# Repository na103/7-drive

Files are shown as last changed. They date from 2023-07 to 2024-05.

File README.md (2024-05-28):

# 7-drive
7-drive is a remake of an Amiga accessory made by the company Logica in Italy, it is installed on the external drive port and can show, in the 7-segment display, the activity of the df0 or df1 drive.
<br>
it's not particularly useful, maybe it was in the past when you spent your time copying hundreds of floppies.<br>
however it seems nice to me as an object to add to our amiga.
<br><br>
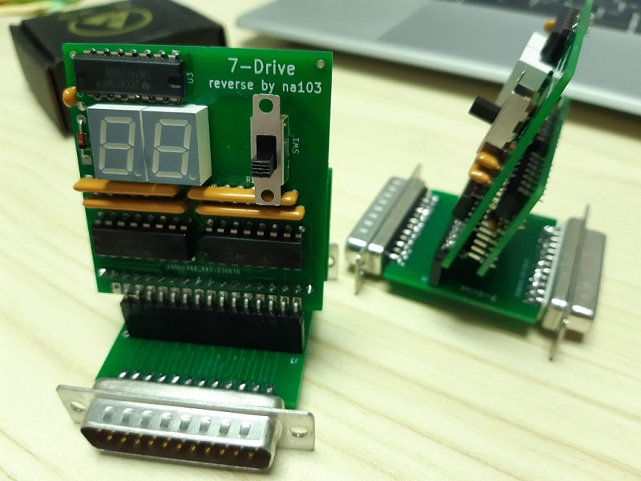
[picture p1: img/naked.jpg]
7-drive

<br>
you can see 7-drive in action in this [short video](https://youtu.be/NdRC49Pznj0)
<br><br>

## Bill of materials
| Qt. | Description | Designator | Mouser  Part | Note |
|:---:|---|---|---|---|
|1 |74LS27 | U2 |SN74LS27N | |
|1 |74LS00 | U3 |SN74LS00N | |
|2 |Decade up-down counter| U4 U5 |CD40110BE | |
|2 |7 segment display | DS1 DS2 |TDSO3160-L | |
|2 |Diode 1N4148 | D1 D2 |1N4148 | |
|1 |Resistor 3.9K | R1 |MFR25SFTE26-3K9 | |
|4 |Resistor net. 220R  | RN1 - RN4 |4608X-102-221LF | |
|1 |Capacitor 4.7 nF | C1 |K472J20C0GF5TH5 | |
|2 |Capacitor 100 nF | C2 C3 |K104K15X7RF5TH5 | |
|1 |Switch 2P3T | SW1 |EG1201A | |
|1 |Db23 male | J1 | | on ebay or [amigatore.eu](https://amigastore.eu/en/790-db23-male-connector.html) |
|1 |Db23 female | J2 | | on ebay or [amigastore.eu](https://amigastore.eu/en/810-db23-female-connector.html) |
|1 |15-Pin female header| J3 |15Fx1-254mm | |
|1 |18-Pin male header  | J5 |22-28-4183 | |
|1 |15-Pin male header  | J6 |22-28-8152 | |

here you can find the mouser project with all the components, Db23 connectors excluded.
[https://www.mouser.com/ProjectManager/ProjectDetail.aspx?AccessID=75b1d9bf4b](https://www.mouser.com/ProjectManager/ProjectDetail.aspx?AccessID=75b1d9bf4b)

## Building notes

* you can see [here](https://github.com/na103/7-drive/tree/main/img) the steps to follow to build the board.
* gerber of the three board is inside kicad projects
* switch in upper position show DF0 activity, down DF1
* is avaible an optional 3d printed case. thanks to Roberto Camparini for stl file

<br>
If you found this my work useful, please consider buying me a cup of coffee if you want:<br>


# License

This work is licensed under a Creative Commons Attribution 4.0 International License. See [https://creativecommons.org/licenses/by/4.0/](https://creativecommons.org/licenses/by/4.0/).

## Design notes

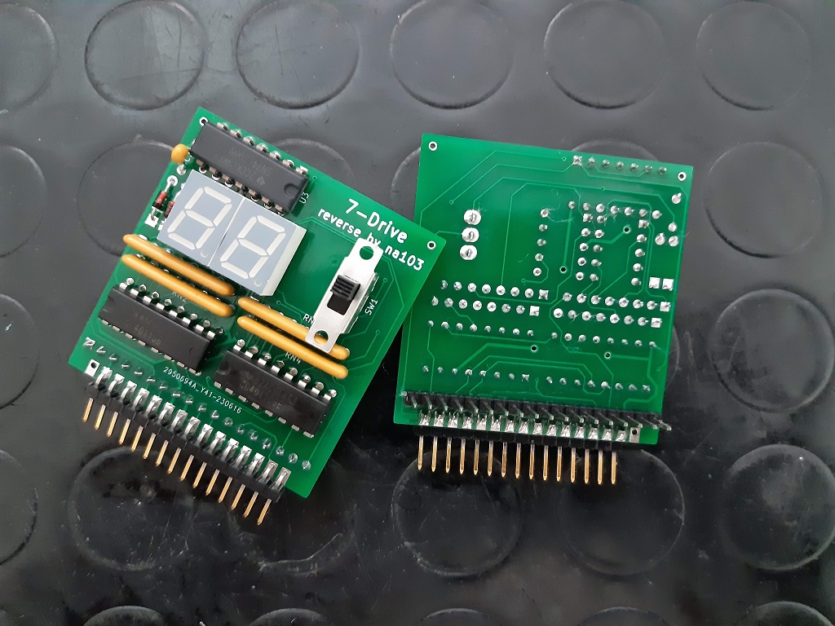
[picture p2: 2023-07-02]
img/cs3.jpg

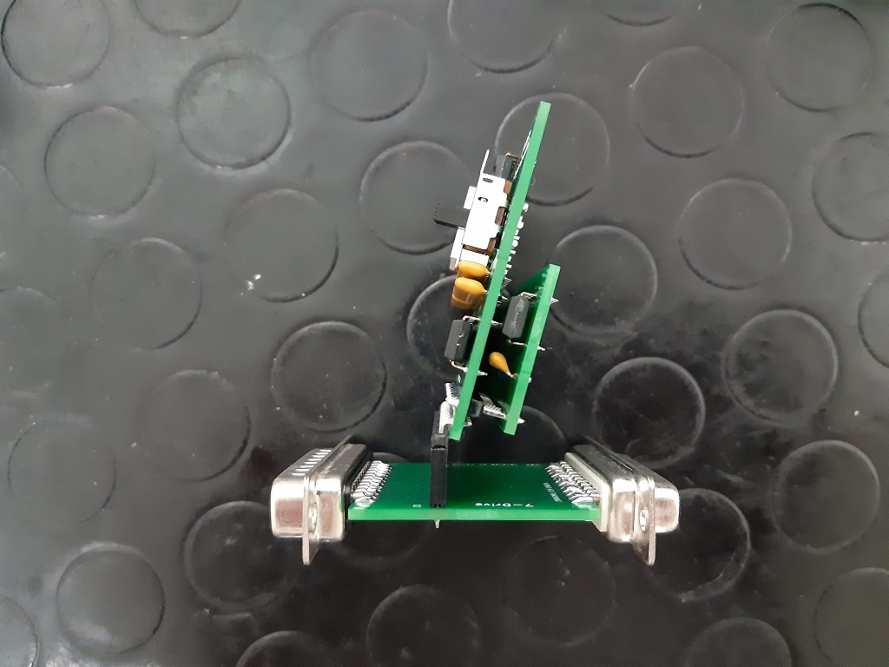
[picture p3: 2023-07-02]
img/cs1_cs2_cs3.jpg

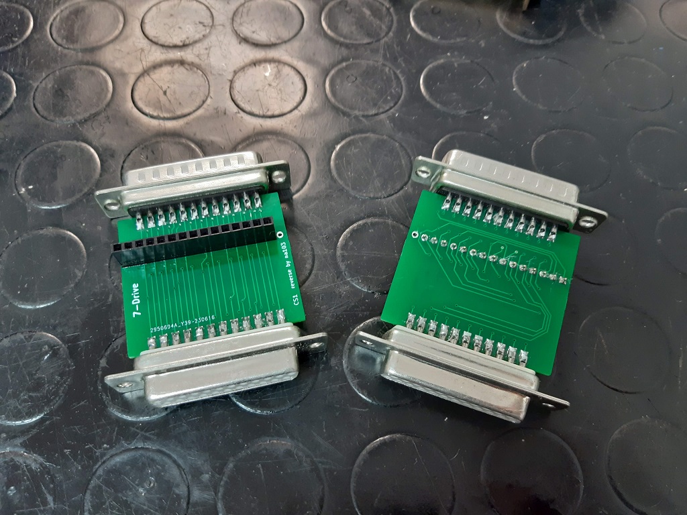
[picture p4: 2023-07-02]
img/cs1.jpg

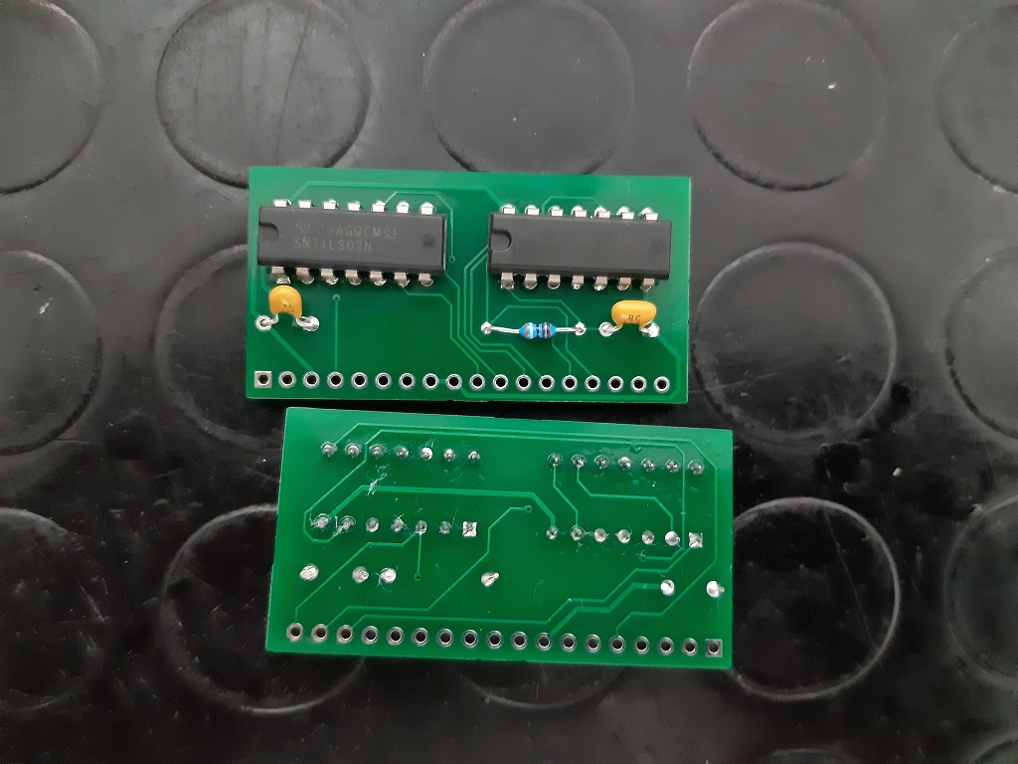
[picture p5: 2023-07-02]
img/cs2.jpg

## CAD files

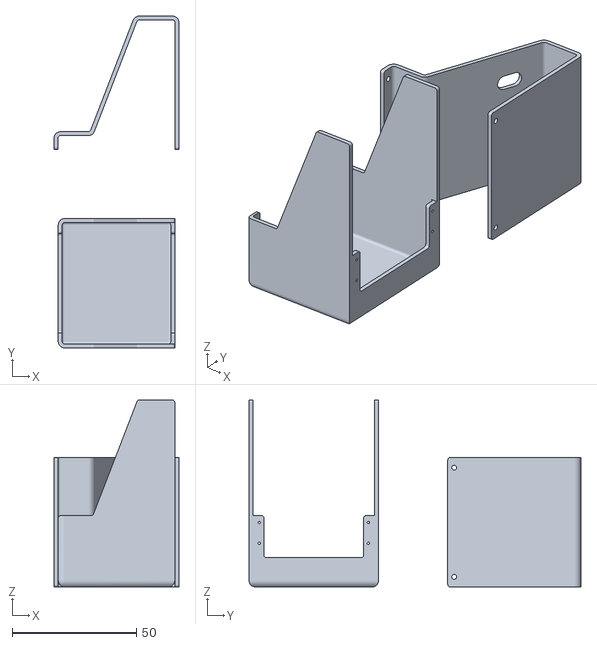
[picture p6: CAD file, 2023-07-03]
3d-print/7-Drive.stl
50.4 x 133.8 x 75.4

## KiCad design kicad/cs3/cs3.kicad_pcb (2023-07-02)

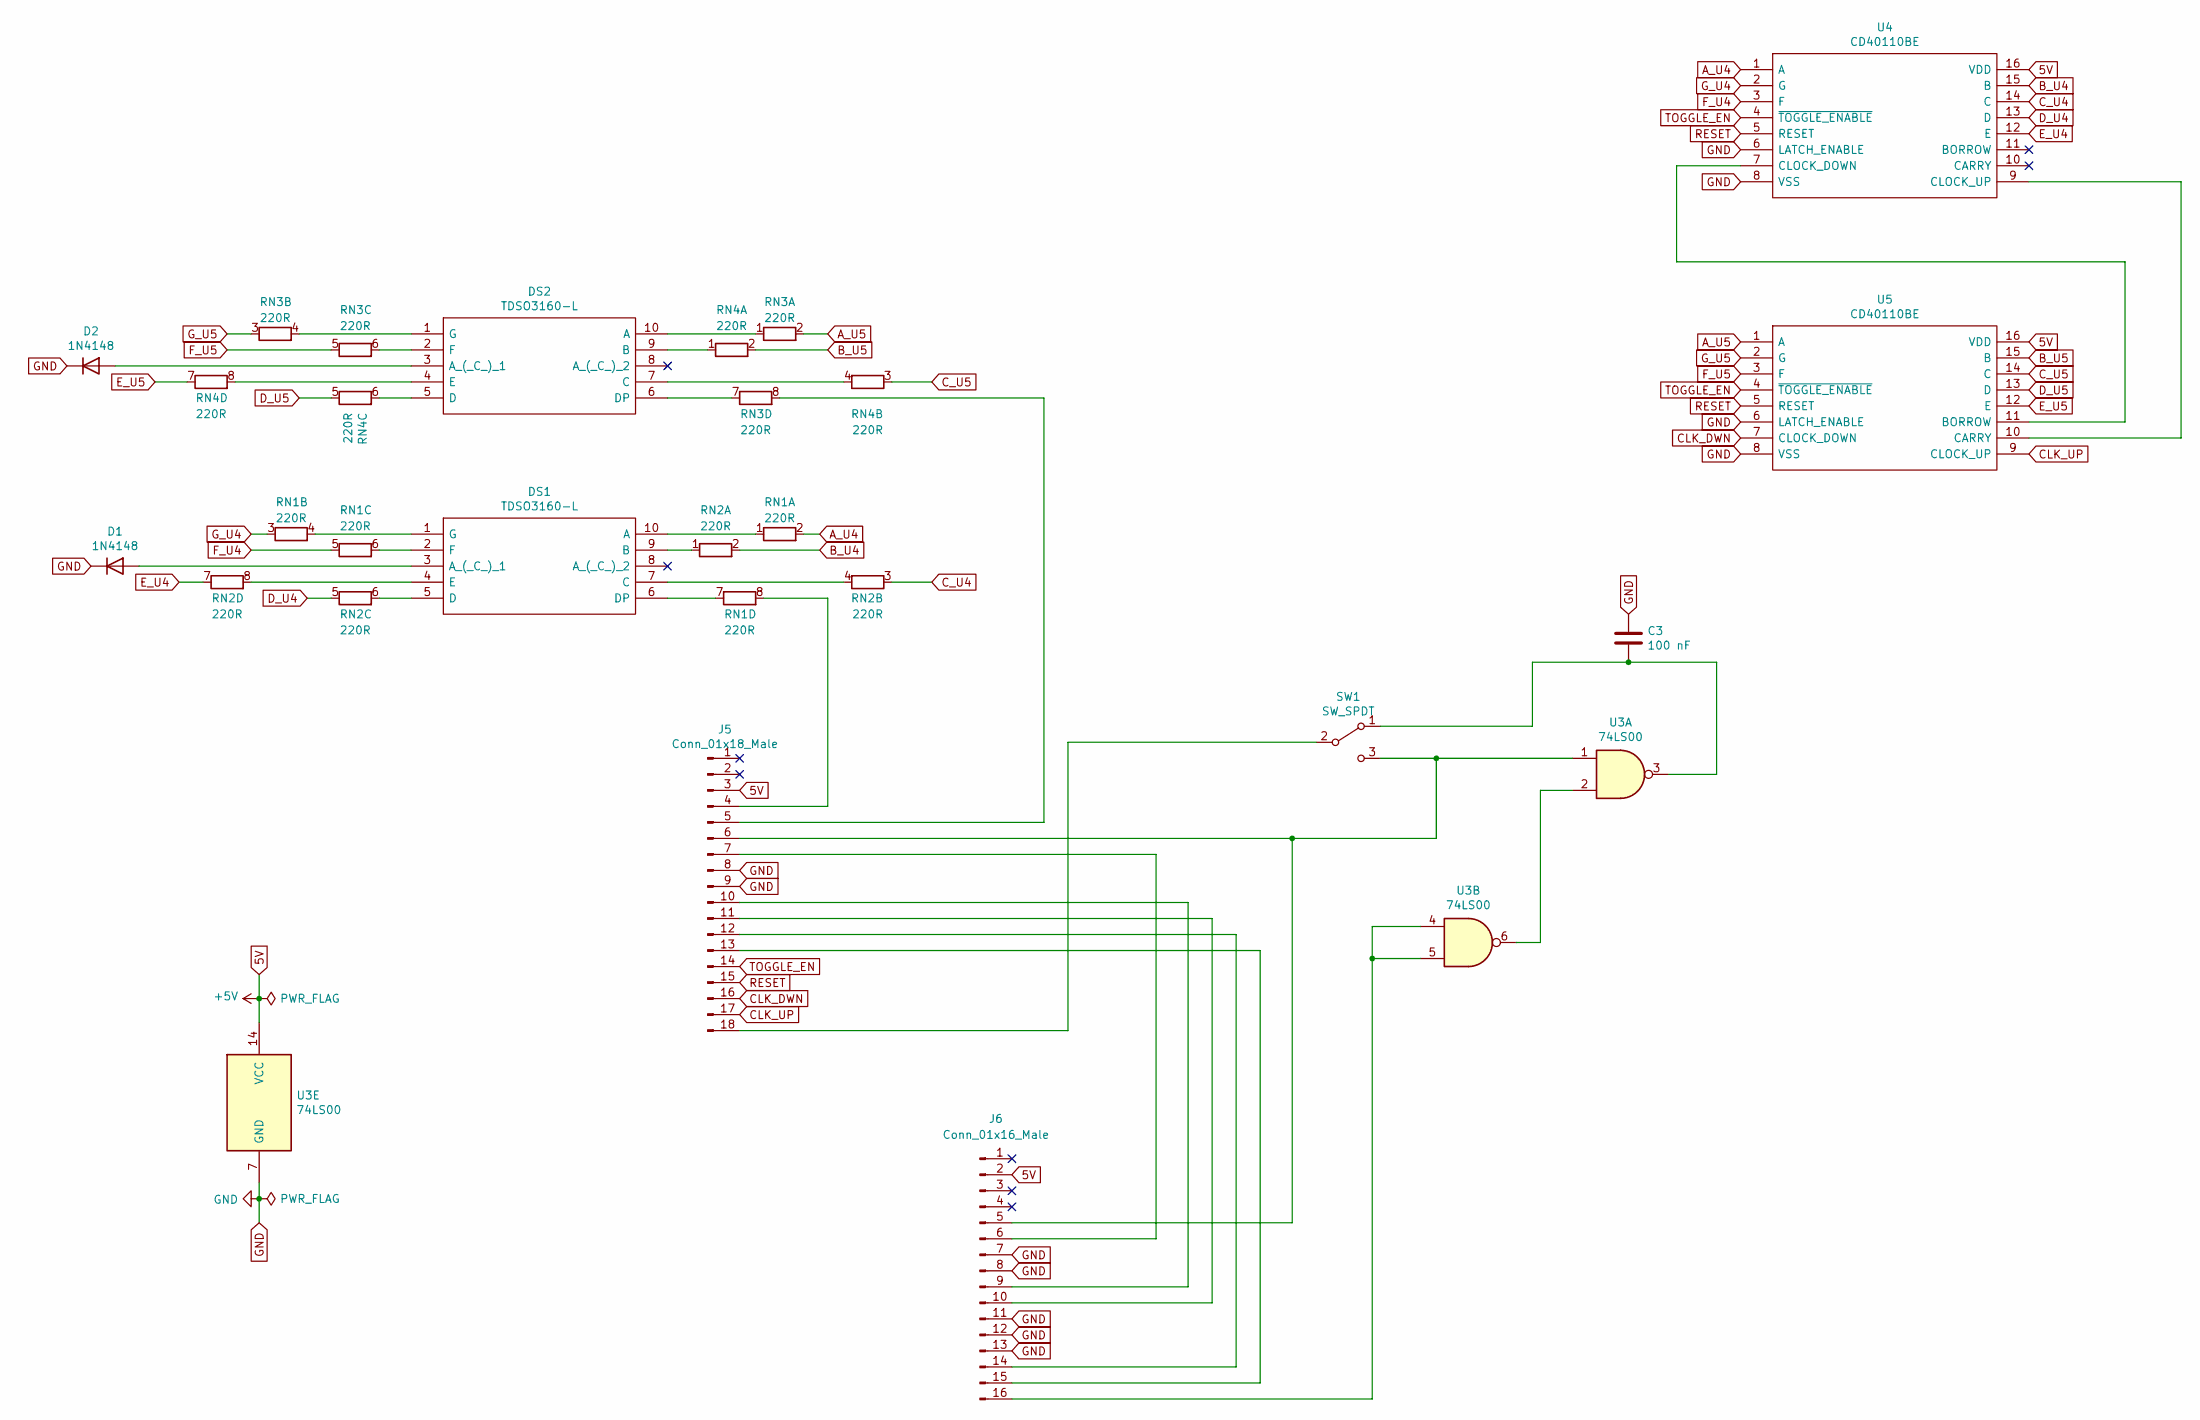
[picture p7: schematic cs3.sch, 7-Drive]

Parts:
C3: 100 nF; C_Disc_D6.0mm_W2.5mm_P5.00mm
D1, D2: 1N4148; D_A-405_P7.62mm_Horizontal
DS1, DS2: TDSO3160-L; TDSO3160L; Manufacturer_Part_Number TDSO3160-L; Mouser Part Number 78-TDSO3160-L
J5: Conn_01x18_Male; PinHeader_1x18_P2.54mm_Vertical
J6: Conn_01x16_Male; PinHeader_1x16_P2.54mm_Horizontal
RN1, RN2, RN3, RN4: 220R; R_Array_SIP8
SW1: SW_SPDT; SW_Slide_1P2T_SPDT
U3: 74LS00; DIP-14_W7.62mm
U4, U5: CD40110BE; DIP794W53P254L1930H508Q16N; Manufacturer_Part_Number CD40110BE; Mouser Part Number 595-CD40110BE

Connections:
5V: J5.3, J6.2, U3.14 (VCC), U4.16 (VDD), U5.16 (VDD)
A_U4: RN1.2 (R1.2), U4.1 (A)
A_U5: RN3.2 (R1.2), U5.1 (A)
B_U4: RN2.2 (R1.2), U4.15 (B)
B_U5: RN4.2 (R1.2), U5.15 (B)
CLK_DWN: J5.16, U5.7 (CLOCK_DOWN)
CLK_UP: J5.17, U5.9 (CLOCK_UP)
C_U4: RN2.3 (R2.1), U4.14 (C)
C_U5: RN4.3 (R2.1), U5.14 (C)
D_U4: RN2.5 (R3.1), U4.13 (D)
D_U5: RN4.5 (R3.1), U5.13 (D)
E_U4: RN2.7 (R4.1), U4.12 (E)
E_U5: RN4.7 (R4.1), U5.12 (E)
F_U4: RN1.5 (R3.1), U4.3 (F)
F_U5: RN3.5 (R3.1), U5.3 (F)
GND: C3.1, D1.1 (K), D2.1 (K), J5.8, J5.9, J6.7, J6.8, J6.11, J6.12, J6.13, U3.7 (GND), U4.6 (LATCH_ENABLE), U4.8 (VSS), U5.6 (LATCH_ENABLE), U5.8 (VSS)
G_U4: RN1.3 (R2.1), U4.2 (G)
G_U5: RN3.3 (R2.1), U5.2 (G)
unnamed: C3.2, SW1.1 (A), U3.3
unnamed: D1.2 (A), DS1.3 (A_(_C_)_1)
unnamed: D2.2 (A), DS2.3 (A_(_C_)_1)
unnamed: DS1.1 (G), RN1.4 (R2.2)
unnamed: DS1.2 (F), RN1.6 (R3.2)
unnamed: DS1.4 (E), RN2.8 (R4.2)
unnamed: DS1.5 (D), RN2.6 (R3.2)
unnamed: DS1.6 (DP), RN1.7 (R4.1)
unnamed: DS1.7 (C), RN2.4 (R2.2)
unnamed: DS1.9 (B), RN2.1 (R1.1)
unnamed: DS1.10 (A), RN1.1 (R1.1)
unnamed: DS2.1 (G), RN3.4 (R2.2)
unnamed: DS2.2 (F), RN3.6 (R3.2)
unnamed: DS2.4 (E), RN4.8 (R4.2)
unnamed: DS2.5 (D), RN4.6 (R3.2)
unnamed: DS2.6 (DP), RN3.7 (R4.1)
unnamed: DS2.7 (C), RN4.4 (R2.2)
unnamed: DS2.9 (B), RN4.1 (R1.1)
unnamed: DS2.10 (A), RN3.1 (R1.1)
unnamed: J5.4, RN1.8 (R4.2)
unnamed: J5.5, RN3.8 (R4.2)
unnamed: J5.6, J6.5, SW1.3 (C), U3.1
unnamed: J5.7, J6.6
unnamed: J5.10, J6.9
unnamed: J5.11, J6.10
unnamed: J5.12, J6.14
unnamed: J5.13, J6.15
unnamed: J5.18, SW1.2 (B)
unnamed: J6.16, U3.4, U3.5
unnamed: U3.2, U3.6
unnamed: U4.7 (CLOCK_DOWN), U5.11 (BORROW)
unnamed: U4.9 (CLOCK_UP), U5.10 (CARRY)
RESET: J5.15, U4.5 (RESET), U5.5 (RESET)
TOGGLE_EN: J5.14, U4.4 (~TOGGLE_ENABLE), U5.4 (~TOGGLE_ENABLE)

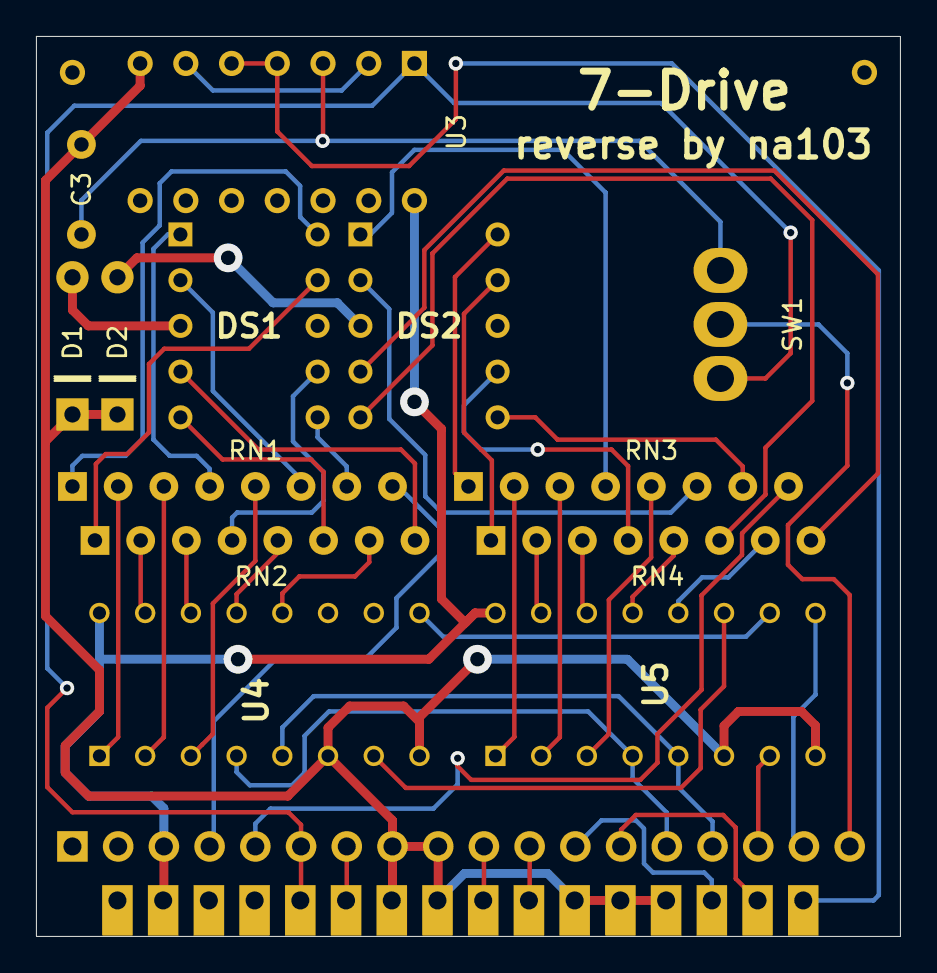
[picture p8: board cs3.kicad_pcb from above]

Board: 2 copper layers, 48.0 x 50.0 mm, 15 parts (1 on the bottom side), 52 nets.

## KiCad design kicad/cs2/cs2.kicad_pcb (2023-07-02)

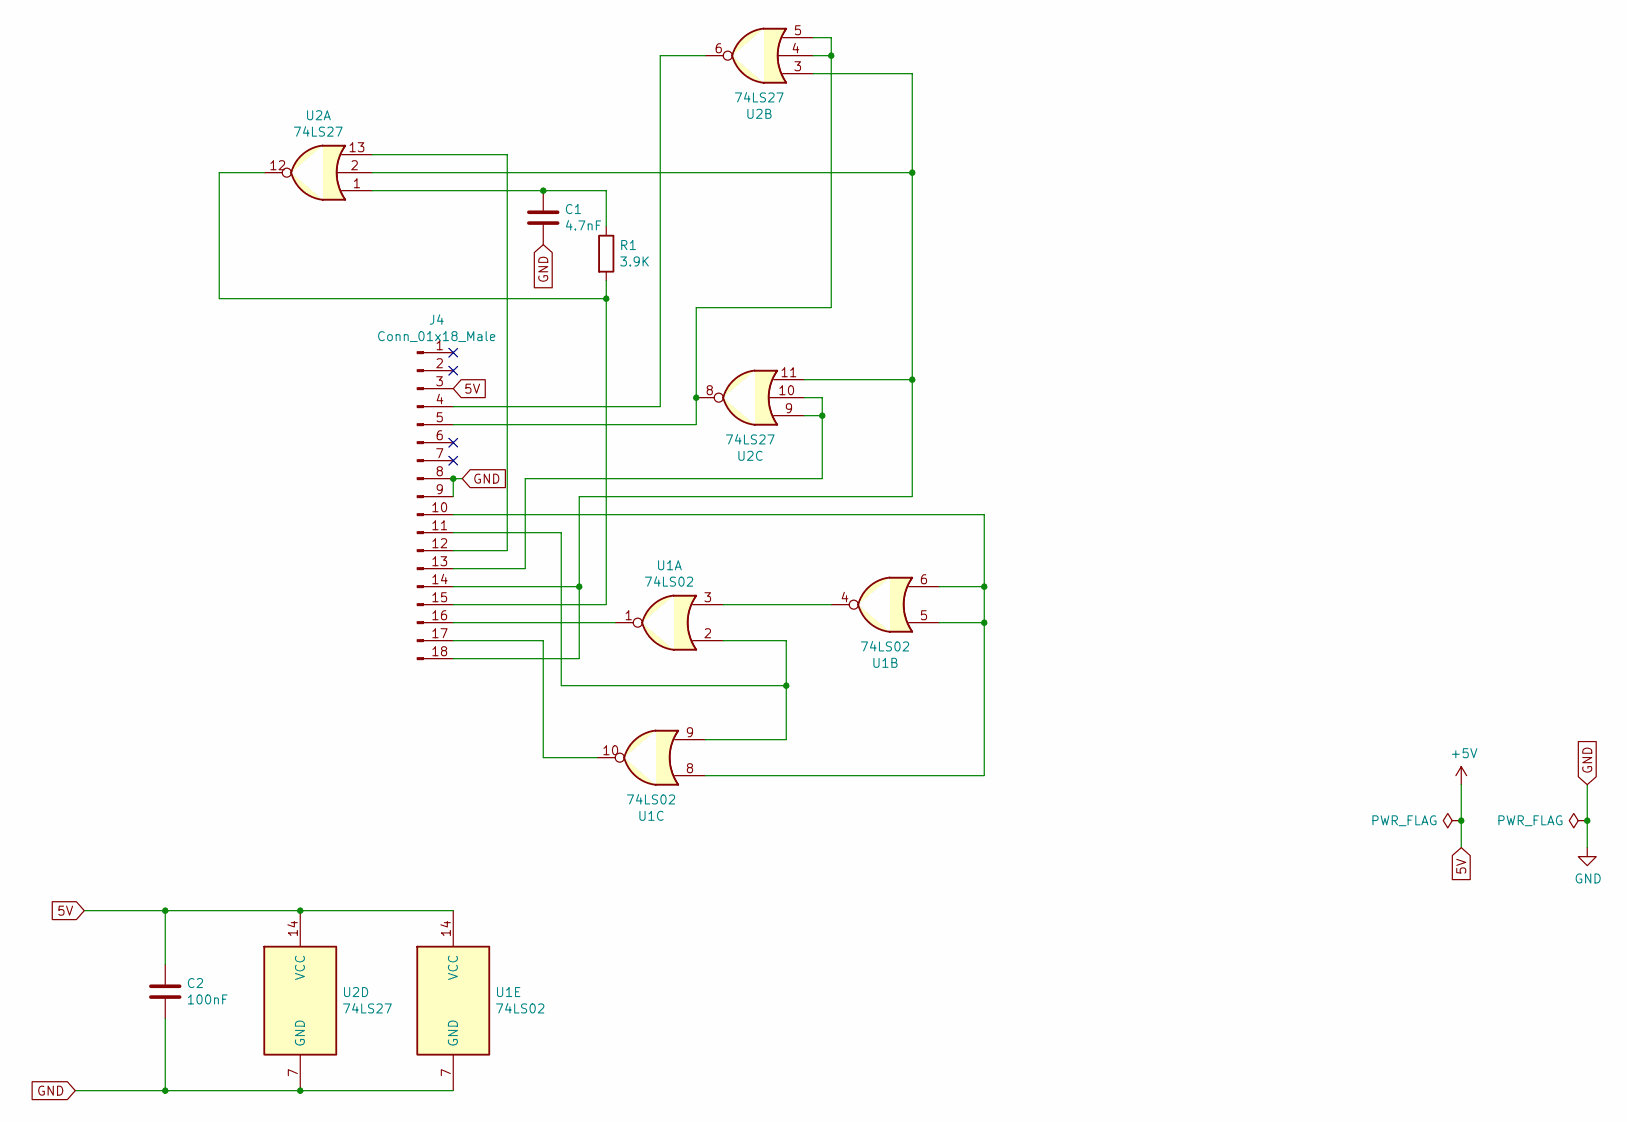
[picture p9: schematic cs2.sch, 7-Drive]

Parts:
C1: 4.7nF; C_Disc_D4.3mm_W1.9mm_P5.00mm
C2: 100nF; C_Disc_D4.3mm_W1.9mm_P5.00mm
J4: Conn_01x18_Male; PinHeader_1x18_P2.54mm_Vertical
R1: 3.9K; R_Axial_DIN0207_L6.3mm_D2.5mm_P10.16mm_Horizontal
U1: 74LS02; DIP-14_W7.62mm
U2: 74LS27; DIP-14_W7.62mm

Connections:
5V: C2.1, J4.3, U1.14 (VCC), U2.14 (VCC)
GND: C1.2, C2.2, J4.8, J4.9, U1.7 (GND), U2.7 (GND)
unnamed: C1.1, R1.1, U2.1
unnamed: J4.4, U2.6
unnamed: J4.5, U2.4, U2.5, U2.8
unnamed: J4.10, U1.5, U1.6, U1.8
unnamed: J4.11, U1.2, U1.9
unnamed: J4.12, U2.13
unnamed: J4.13, U2.9, U2.10
unnamed: J4.14, J4.18, U2.2, U2.3, U2.11
unnamed: J4.15, R1.2, U2.12
unnamed: J4.16, U1.1
unnamed: J4.17, U1.10
unnamed: U1.3, U1.4

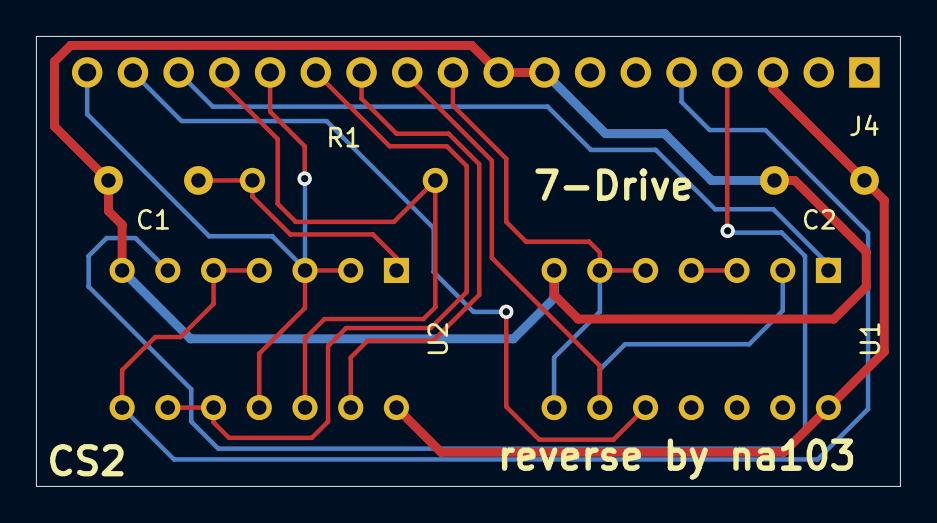
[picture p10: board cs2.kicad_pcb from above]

Board: 2 copper layers, 48.0 x 25.0 mm, 6 parts (0 on the bottom side), 14 nets.

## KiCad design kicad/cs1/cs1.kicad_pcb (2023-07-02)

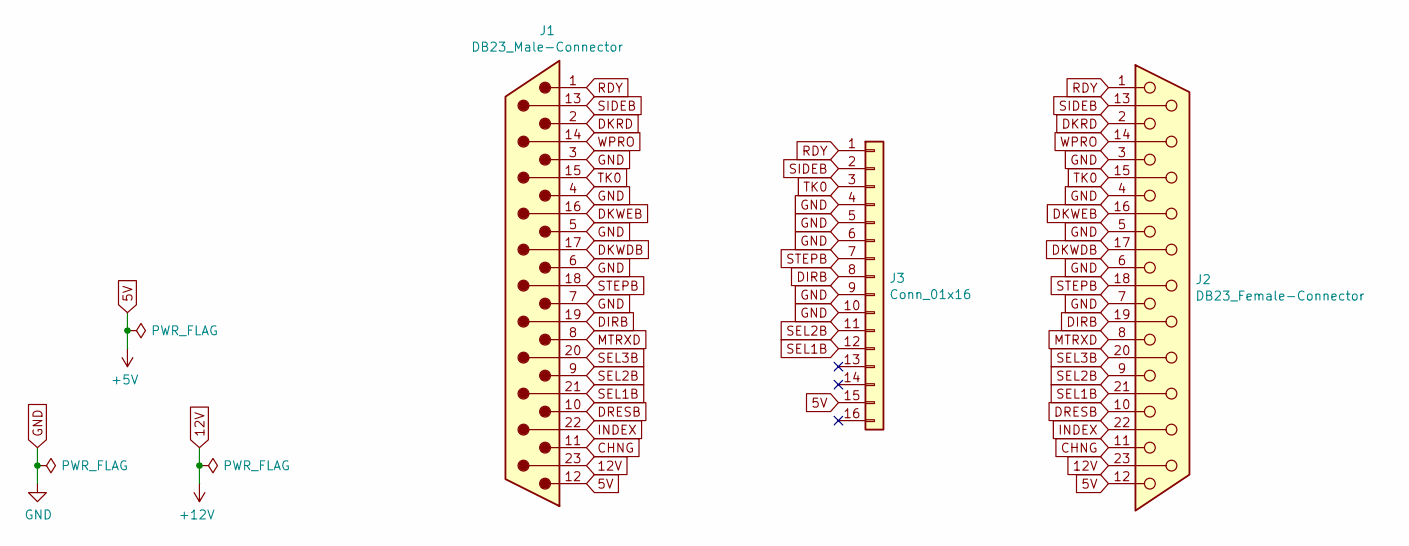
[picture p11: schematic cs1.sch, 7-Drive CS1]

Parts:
J1: DB23_Male-Connector; DSUB-23_Male_EdgeMount_P2.77mm
J2: DB23_Female-Connector; DSUB-23_Female_EdgeMount_P2.77mm
J3: Conn_01x16; PinHeader_1x16_P2.54mm_Vertical

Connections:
5V: J1.12, J2.12, J3.15
12V: J1.23, J2.23
CHNG: J1.11, J2.11
DIRB: J1.19, J2.19, J3.8
DKRD: J1.2, J2.2
DKWDB: J1.17, J2.17
DKWEB: J1.16, J2.16
DRESB: J1.10, J2.10
GND: J1.3, J1.4, J1.5, J1.6, J1.7, J2.3, J2.4, J2.5, J2.6, J2.7, J3.4, J3.5, J3.6, J3.9, J3.10
INDEX: J1.22, J2.22
MTRXD: J1.8, J2.8
RDY: J1.1, J2.1, J3.1
SEL1B: J1.21, J2.21, J3.12
SEL2B: J1.9, J2.9, J3.11
SEL3B: J1.20, J2.20
SIDEB: J1.13, J2.13, J3.2
STEPB: J1.18, J2.18, J3.7
TK0: J1.15, J2.15, J3.3
WPRO: J1.14, J2.14

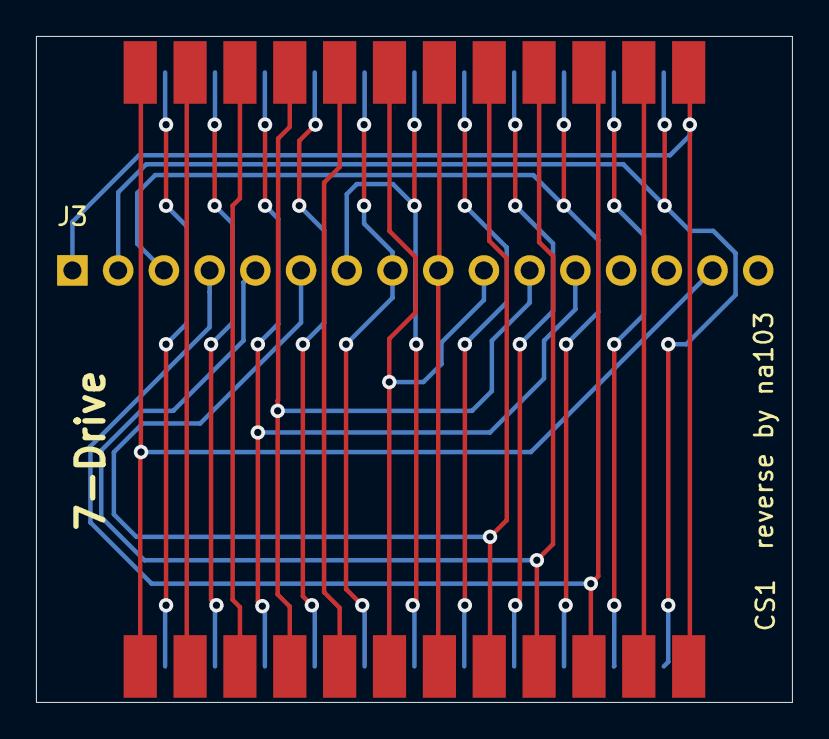
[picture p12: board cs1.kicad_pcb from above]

Board: 2 copper layers, 42.0 x 37.0 mm, 3 parts (0 on the bottom side), 19 nets.

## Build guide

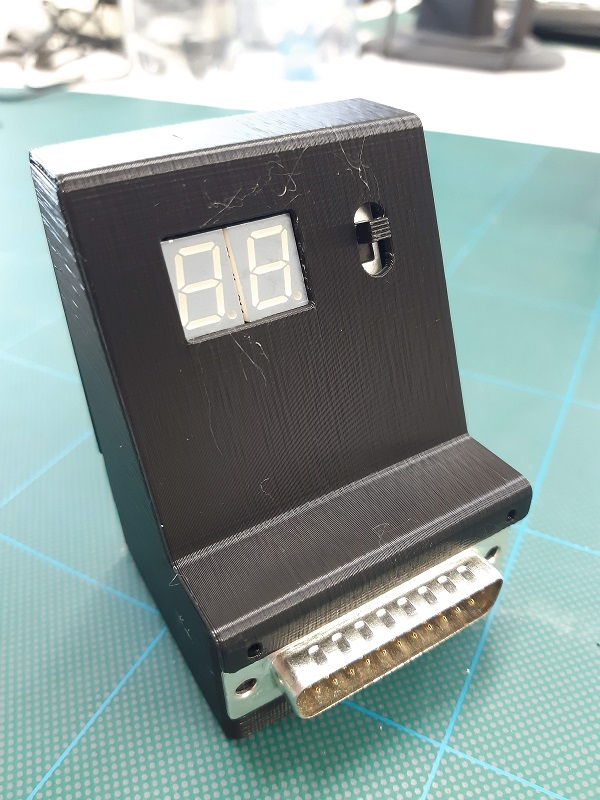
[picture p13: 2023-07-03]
3d-print/case_2.jpg

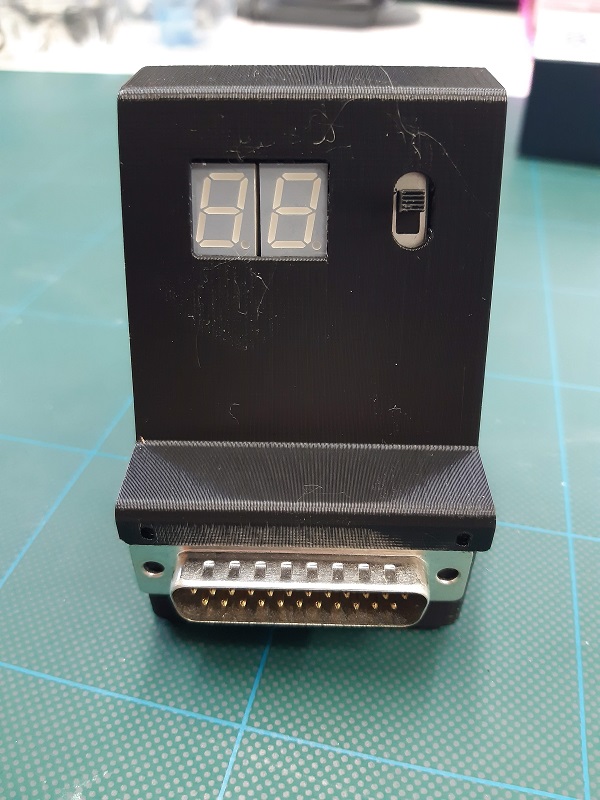
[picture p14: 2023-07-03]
3d-print/case_1.jpg

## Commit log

2023-07-02 Kicad projects
    [cs1-B_Cu.gbr, cs1-B_Mask.gbr, cs1-B_Paste.gbr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]
2023-07-03 case picture
